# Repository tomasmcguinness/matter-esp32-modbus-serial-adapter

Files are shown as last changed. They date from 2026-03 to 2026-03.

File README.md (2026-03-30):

# Matter ESP32 Modbus Adapter
The goal of this project is to provide a simple working Modbus adapter that can expose devices over Matter. It is designed for the ESP32 MCU.

# SDM120M - Electrical Sensor

The first device supported by this project is the Eastron SDM120M Single Phase Energy Meter

The readings from this device will be exposed using as a Matter Electrical Sensor Device Type.

# Hardware - Seeed XIAO ESP32-C6

The GPIOs in code has been selected for the XIAO ESP32-C6. 

| GPIO | Connection |
|---|---|
| 16 | MAX485 - DI | 
| 17 | MAX485 - RO |
| 21 | MAX485 - DE/RE|
| 22 | OLED - SDA |
| 23 | OLED - SCL |
| 2  | OLED - RESET |

Ensure there is a 120kΩ across PINS A&B of the MAX485.

The RESET net label refers to the OLED display. I couldn't find a Fritzing symbol for it.



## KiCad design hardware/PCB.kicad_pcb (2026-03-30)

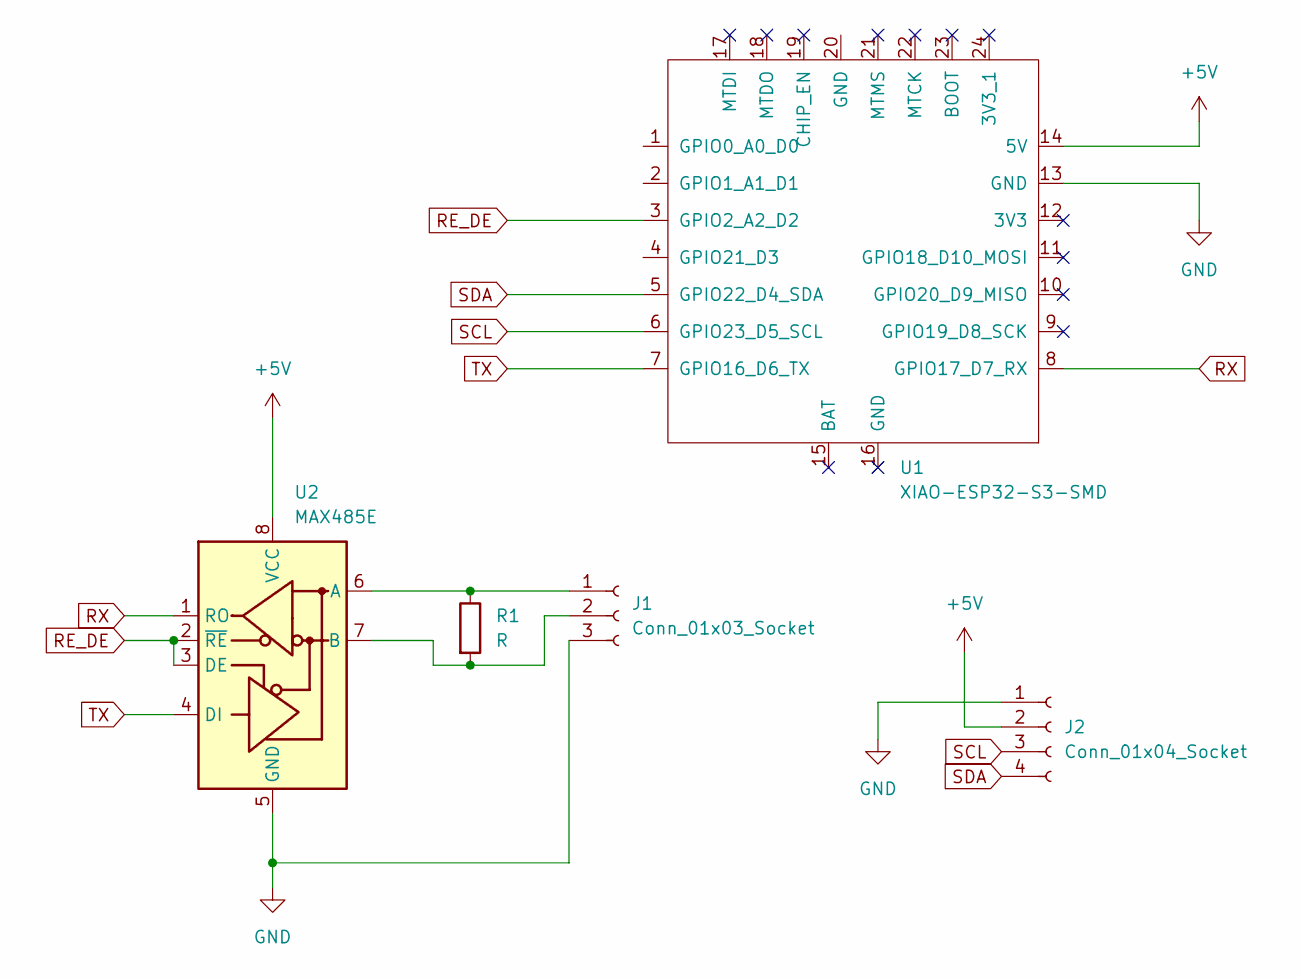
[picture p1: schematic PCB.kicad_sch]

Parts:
J1: Conn_01x03_Socket; PhoenixContact_SPT_1.5_3-H-3.5_1x03_P3.5mm_Horizontal
J2: Conn_01x04_Socket; PinHeader_1x04_P2.54mm_Vertical
R1: R; R_0805_2012Metric
U1: XIAO-ESP32-S3-SMD; XIAO-ESP32C6-SMD
U2: MAX485E; SOIC-8_3.9x4.9mm_P1.27mm

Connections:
+5V: J2.2, U1.14 (5V), U2.8 (VCC)
GND: J1.3, J2.1, U1.13 (GND), U2.5 (GND)
unnamed: J1.1, R1.1, U2.6 (A)
unnamed: J1.2, R1.2, U2.7 (B)
RE_DE: U1.3 (GPIO2_A2_D2), U2.2 (~RE), U2.3 (DE)
RX: U1.8 (GPIO17_D7_RX), U2.1 (RO)
SCL: J2.3, U1.6 (GPIO23_D5_SCL)
SDA: J2.4, U1.5 (GPIO22_D4_SDA)
TX: U1.7 (GPIO16_D6_TX), U2.4 (DI)

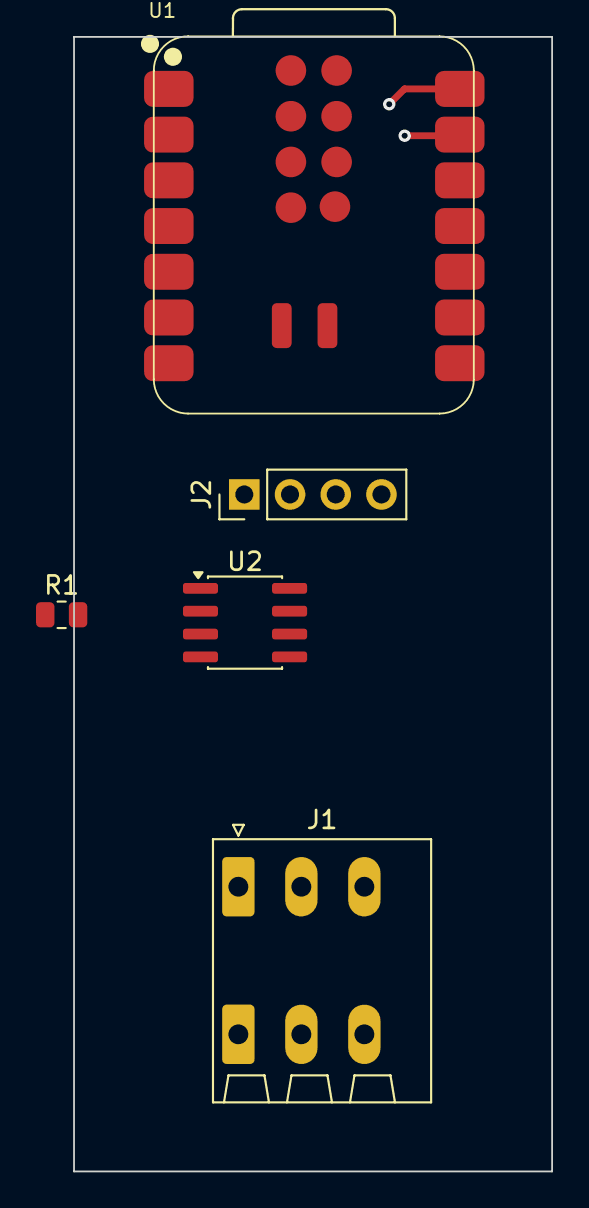
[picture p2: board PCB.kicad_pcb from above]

Board: 2 copper layers, 26.6 x 63.0 mm, 5 parts (0 on the bottom side), 9 nets.

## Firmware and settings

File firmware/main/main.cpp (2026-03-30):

#include <esp_err.h>
#include <esp_log.h>
#include <esp_matter.h>
#include <nvs_flash.h>

#include <app/server/CommissioningWindowManager.h>
#include <app/server/Server.h>
#include <setup_payload/OnboardingCodesUtil.h>
#include <setup_payload/QRCodeSetupPayloadGenerator.h>

#include "modbus.h"
#include "sdm120.h"

#include "freertos/FreeRTOS.h"
#include "freertos/task.h"

#include "status_display.h"
#include "electrical_power_measurement_delegate.h"

static chip::app::Clusters::ElectricalPowerMeasurement::ElectricalPowerMeasurementDelegate EPMDelegate;

static const char *TAG = "Main";

using namespace esp_matter;
using namespace esp_matter::attribute;
using namespace esp_matter::cluster;
using namespace esp_matter::endpoint;

using namespace chip::app::Clusters;

static uint16_t electrical_sensor_endpoint_id = 0;

#define ABORT_APP_ON_FAILURE(x, ...)               \
    do                                             \
    {                                              \
        if (!(unlikely(x)))                        \
        {                                          \
            __VA_ARGS__;                           \
            vTaskDelay(5000 / portTICK_PERIOD_MS); \
            abort();                               \
        }                                          \
    } while (0)

static void open_commissioning_window_if_necessary()
{
    VerifyOrReturn(chip::Server::GetInstance().GetFabricTable().FabricCount() == 0);

    chip::CommissioningWindowManager &mgr = chip::Server::GetInstance().GetCommissioningWindowManager();
    VerifyOrReturn(mgr.IsCommissioningWindowOpen() == false);

    CHIP_ERROR err = mgr.OpenBasicCommissioningWindow(
        chip::System::Clock::Seconds16(300),
        chip::CommissioningWindowAdvertisement::kDnssdOnly);

    if (err != CHIP_NO_ERROR)
    {
        ESP_LOGE(TAG, "Failed to open commissioning window: %" CHIP_ERROR_FORMAT, err.Format());
    }
}

static void app_event_cb(const ChipDeviceEvent *event, intptr_t arg)
{
    switch (event->Type)
    {
    case chip::DeviceLayer::DeviceEventType::kCommissioningComplete:
        ESP_LOGI(TAG, "Commissioning complete");
        break;
    case chip::DeviceLayer::DeviceEventType::kCommissioningWindowClosed:
        ESP_LOGI(TAG, "Commissioning window closed");
        StatusDisplayMgr().ClearCommissioningCode();
        break;
    case chip::DeviceLayer::DeviceEventType::kCommissioningWindowOpened:
    {
        ESP_LOGI(TAG, "Commissioning window opened");

        chip::RendezvousInformationFlags rendezvousFlags = chip::RendezvousInformationFlags(chip::RendezvousInformationFlag::kBLE);

        chip::PayloadContents payload;
        GetPayloadContents(payload, rendezvousFlags);

        char payloadBuffer[chip::QRCodeBasicSetupPayloadGenerator::kMaxQRCodeBase38RepresentationLength + 1];
        chip::MutableCharSpan qrCode(payloadBuffer);

        if (GetQRCode(qrCode, payload) == CHIP_NO_ERROR)
        {
            ESP_LOGI(TAG, "Generated QR CODE [%d]: %s", qrCode.size(), qrCode.data());
            StatusDisplayMgr().SetCommissioningCode(qrCode.data(), qrCode.size());
        }
        else
        {
            ESP_LOGE(TAG, "Failed to generate the commissioning QR code");
        }
        break;
    }
    case chip::DeviceLayer::DeviceEventType::kFabricRemoved:
        ESP_LOGI(TAG, "Fabric removed");
        open_commissioning_window_if_necessary();
        break;
    case chip::DeviceLayer::DeviceEventType::kBLEDeinitialized:
        ESP_LOGI(TAG, "BLE deinitialized");
        break;
    default:
        break;
    }
}

static esp_err_t app_identification_cb(identification::callback_type_t type, uint16_t endpoint_id,
                                       uint8_t effect_id, uint8_t effect_variant, void *priv_data)
{
    return ESP_OK;
}

extern "C" void matter_update_voltage(float voltage_v)
{
    chip::DeviceLayer::SystemLayer().ScheduleLambda([voltage_v] {
        EPMDelegate.SetVoltage(chip::app::DataModel::MakeNullable((int64_t)(voltage_v * 1000.0f))); // V → mV
    });
}

extern "C" void matter_update_current(float current_a)
{
    chip::DeviceLayer::SystemLayer().ScheduleLambda([current_a] {
        EPMDelegate.SetActiveCurrent(chip::app::DataModel::MakeNullable((int64_t)(current_a * 1000.0f))); // A → mA
    });
}

extern "C" void matter_update_power(float power_w)
{
    chip::DeviceLayer::SystemLayer().ScheduleLambda([power_w] {
        EPMDelegate.SetActivePower(chip::app::DataModel::MakeNullable((int64_t)(power_w * 1000.0f))); // W → mW
    });
}

static esp_err_t app_attribute_update_cb(attribute::callback_type_t type, 
                                         uint16_t endpoint_id,
                                         uint32_t cluster_id, 
                                         uint32_t attribute_id,
                                         esp_matter_attr_val_t *val, 
                                         void *priv_data)
{
    return ESP_OK;
}

extern "C" void app_main()
{
    nvs_flash_init();

    StatusDisplayMgr().Init();
    StatusDisplayMgr().TurnOn();
    ESP_LOGI(TAG, "Display initialized");

    modbus_uart_init();
    ESP_LOGI(TAG, "Modbus UART initialized");

    // Create the root endpoint
    node::config_t node_config;
    node_t *node = node::create(&node_config, app_attribute_update_cb, app_identification_cb);
    ABORT_APP_ON_FAILURE(node != nullptr, ESP_LOGE(TAG, "Failed to create Matter node"));

    electrical_sensor::config_t electrical_sensor_config;
    // Configure the sensor as a node.
    electrical_sensor_config.power_topology.feature_flags = power_topology::feature::node_topology::get_id();

    // Configure AC as the power type.
    electrical_sensor_config.electrical_power_measurement.feature_flags = electrical_power_measurement::feature::alternating_current::get_id();
    electrical_sensor_config.electrical_power_measurement.delegate = &EPMDelegate;

    endpoint_t *endpoint = electrical_sensor::create(node, &electrical_sensor_config, ENDPOINT_FLAG_NONE, NULL);
    ABORT_APP_ON_FAILURE(endpoint != nullptr, ESP_LOGE(TAG, "Failed to create electrical sensor endpoint"));
    electrical_sensor_endpoint_id = endpoint::get_id(endpoint);

    cluster_t *cluster = cluster::get(endpoint, chip::app::Clusters::ElectricalPowerMeasurement::Id);
    ABORT_APP_ON_FAILURE(cluster != nullptr, ESP_LOGE(TAG, "Failed to get EPM cluster from endpoint"));

    electrical_power_measurement::attribute::create_voltage(cluster, 0);
    electrical_power_measurement::attribute::create_active_current(cluster, 0);
    electrical_power_measurement::attribute::create_active_power(cluster, 0);

    esp_err_t err = esp_matter::start(app_event_cb);
    if (err != ESP_OK)
    {
        ESP_LOGE(TAG, "Failed to start Matter: %d", err);
        return;
    }

    xTaskCreate(sdm120_read_task, "sdm120m_read", 4096, NULL, 5, NULL);
}

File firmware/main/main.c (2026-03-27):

#include "modbus.h"
#include "sdm120.h"
#include "freertos/FreeRTOS.h"
#include "freertos/task.h"
#include "esp_log.h"

static const char *TAG = "Main";

void app_main(void)
{
    modbus_uart_init();
    ESP_LOGI(TAG, "Modbus UART initialized");

    xTaskCreate(sdm120_read_task, "sdm120m_read", 2048, NULL, 5, NULL);
}

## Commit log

2026-03-20 Add project description for Matter ESP32 Modbus Adapter
2026-03-27 Add Matter support. Refactor to split out the SDM read. Add partitions.csv
    [partitions.csv]
2026-03-28 QR Code is showing correctly.
    [main.cpp, status_display.cpp]
2026-03-29 Fix C -> CPP changes. Tweak readme.
    [main.cpp, modbus.cpp]
2026-03-30 Move code into a firmware folder
    [partitions.csv]
2026-03-30 Push PIN connections
2026-03-30 Schematic updated
    [PCB.kicad_pcb, PCB.kicad_sch, Sketch.fzz]
2026-04-01 Two PCB tweaks
2026-04-01 PCB Backup
